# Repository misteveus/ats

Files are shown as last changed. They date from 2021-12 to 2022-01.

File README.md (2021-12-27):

# ats

## Remote
- 3.3v power and ground header
    - No OVP
    - No OCP
    - No polarity protection
    - Modules have their own decoupling caps
    - Modules have decoupling capacitors
- SPI header for LoRa module debug
- UART header for GPS module debug
- ICSP header for programming the PIC18
- LoRa module and SMD antenna
- GPS module and SMD antenna
- PIC18 controller
    - Controls SPI and UART

remote schematic  

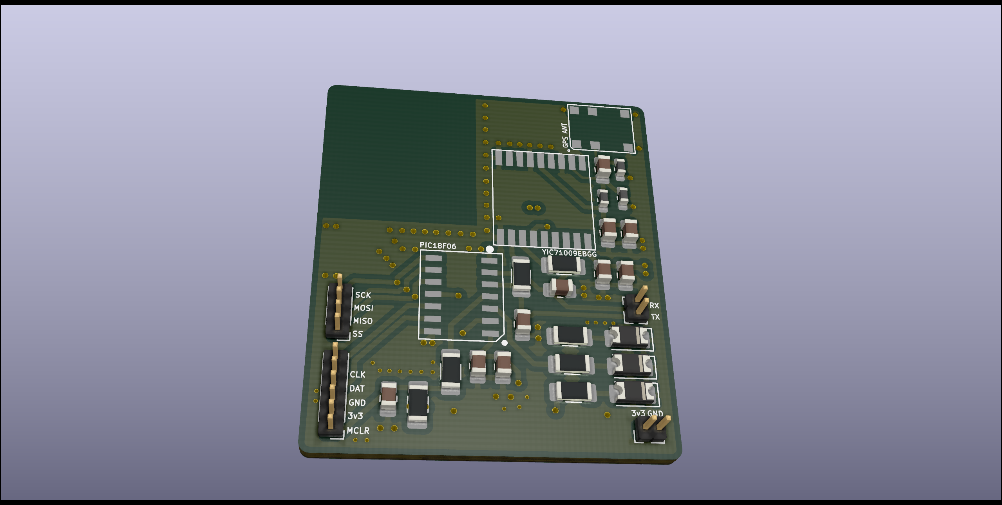
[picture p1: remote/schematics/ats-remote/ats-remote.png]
remote pcb
  

## References
Microcontroller PIC18F06Q40 [datasheet](https://ww1.microchip.com/downloads/aemDocuments/documents/MCU08/ProductDocuments/DataSheets/PIC18F06-16Q40-Data-Sheet-40002216D.pdf)  
LoRa Tranceiver RFM95W [datasheet](https://www.rfsolutions.co.uk/downloads/1463993415RFM95_96_97_98W.pdf)  
GPS/GLONASS Receiver YIC71009EBGG [datasheet](https://www.yic.com.tw/wp-content/uploads/2021/05/YIC71009EBGG.pdf)

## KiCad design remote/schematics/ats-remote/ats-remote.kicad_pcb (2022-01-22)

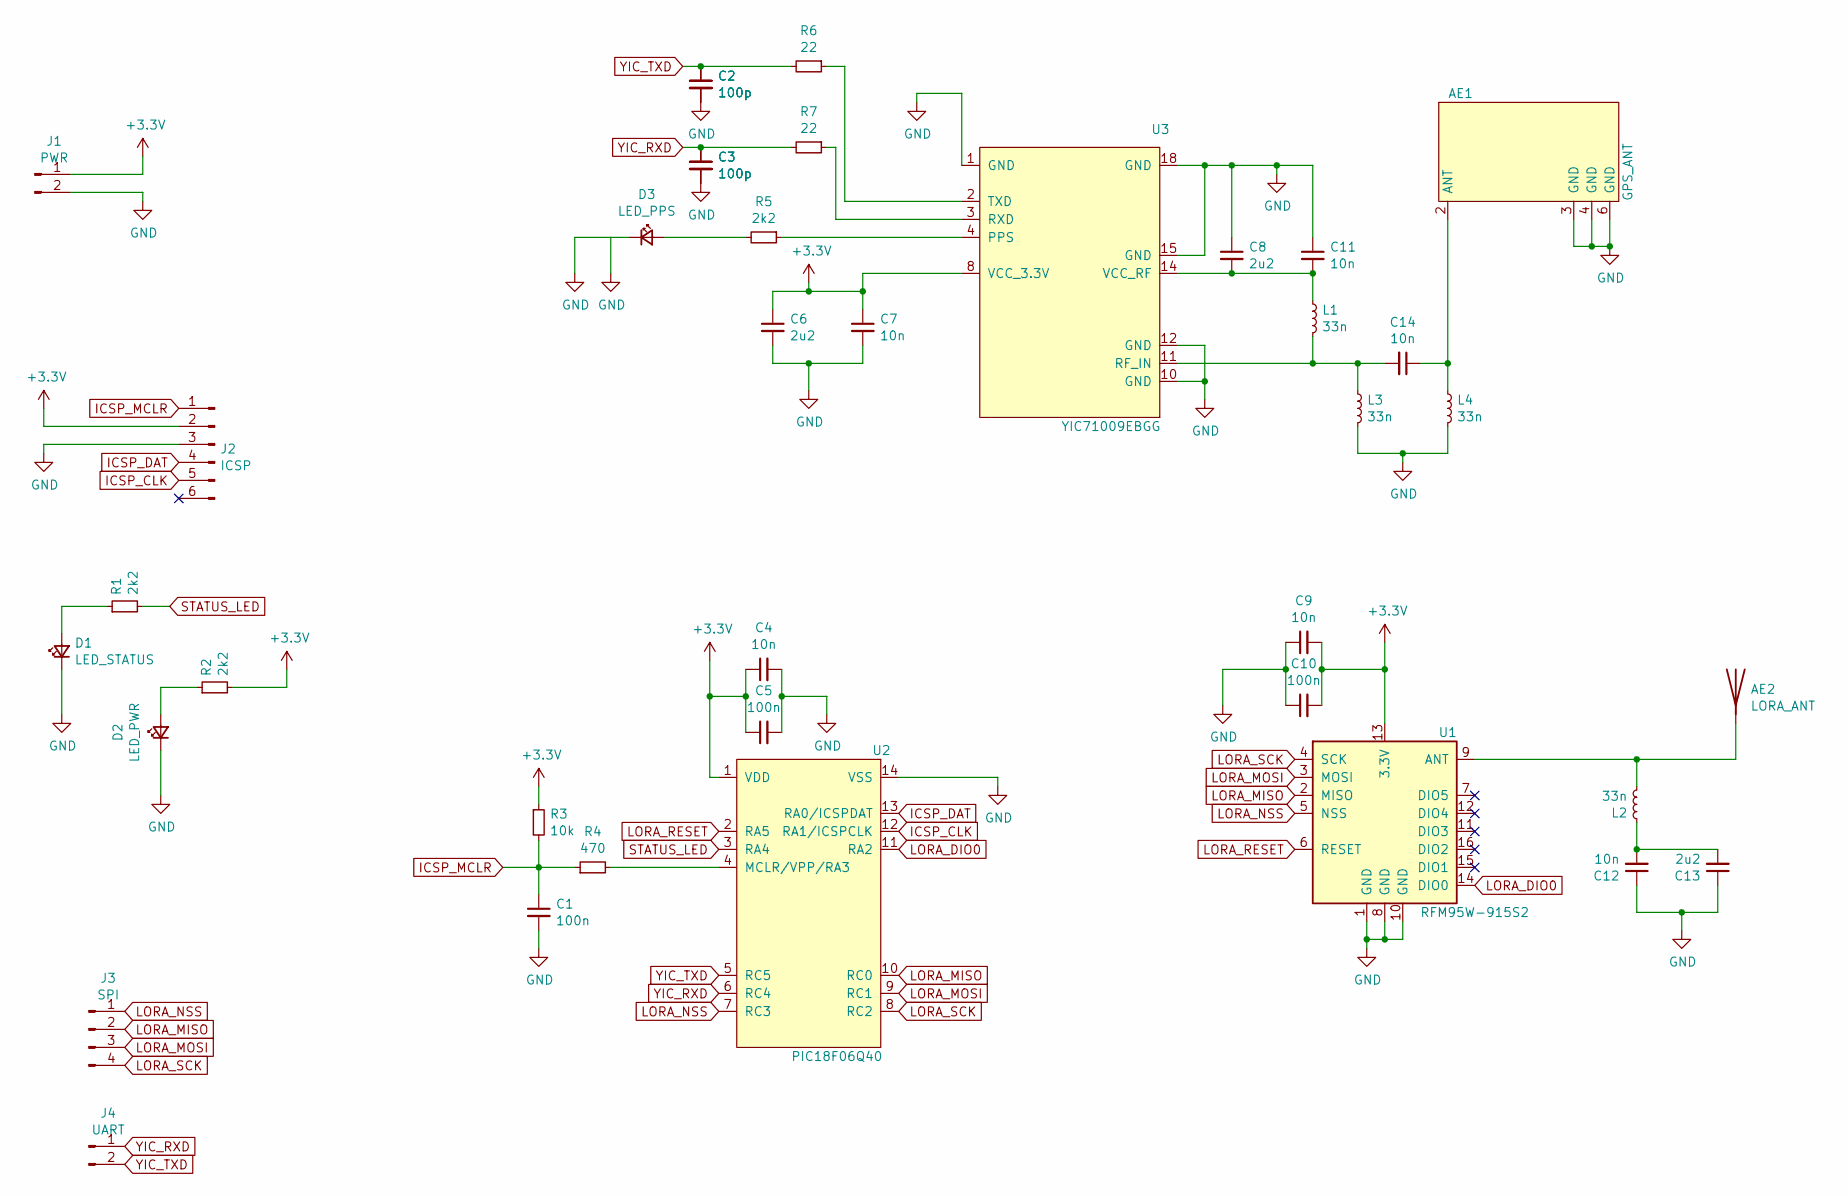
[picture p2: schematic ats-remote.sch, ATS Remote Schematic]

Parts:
AE1: GPS_ANT; GPS_ANT_SR4G008
AE2: LORA_ANT; LORA_ANT_YIC71009EBGG
C1, C5, C10: 100n; C_0805_2012Metric_Pad1.18x1.45mm_HandSolder
C2, C3: 100p; C_0805_2012Metric_Pad1.18x1.45mm_HandSolder
C4, C7, C9, C11, C12, C14: 10n; C_0805_2012Metric_Pad1.18x1.45mm_HandSolder
C6, C8, C13: 2u2; C_0805_2012Metric_Pad1.18x1.45mm_HandSolder
D1: LED_STATUS; D_1206_3216Metric_Pad1.42x1.75mm_HandSolder
D2: LED_PWR; D_1206_3216Metric_Pad1.42x1.75mm_HandSolder
D3: LED_PPS; D_1206_3216Metric_Pad1.42x1.75mm_HandSolder
J1: PWR; PinHeader_1x02_P1.27mm_Vertical
J2: ICSP; PinHeader_1x06_P1.27mm_Vertical
J3: SPI; PinHeader_1x04_P1.27mm_Vertical
J4: UART; PinHeader_1x02_P1.27mm_Vertical
L1, L2, L3, L4: 33n; L_0603_1608Metric_Pad1.05x0.95mm_HandSolder
R1, R2, R5: 2k2; R_1206_3216Metric_Pad1.30x1.75mm_HandSolder
R3: 10k; R_1206_3216Metric_Pad1.30x1.75mm_HandSolder
R4: 470; R_1206_3216Metric_Pad1.30x1.75mm_HandSolder
R6, R7: 22; R_1206_3216Metric_Pad1.30x1.75mm_HandSolder
U1: RFM95W-915S2; HOPERF_RFM9XW_SMD
U2: PIC18F06Q40; PIC18F06Q40-SOIC14
U3: YIC71009EBGG; YIC71009EBGG-19STAMP

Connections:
+3V3: C4.1, C5.1, C6.1, C7.1, C9.2, C10.2, J1.1, J2.2, R2.2, R3.1, U1.13 (3.3V), U2.1 (VDD), U3.8 (VCC_3.3V)
GND: AE1.3 (GND), AE1.4 (GND), AE1.6 (GND), C1.2, C2.2, C3.2, C4.2, C5.2, C6.2, C7.2, C8.1, C9.1, C10.1, C11.1, C12.1, C13.1, D1.1 (K), D2.1 (K), D3.1 (K), J1.2, J2.3, L3.2, L4.2, U1.1 (GND), U1.8 (GND), U1.10 (GND), U2.14 (VSS), U3.1 (GND), U3.10 (GND), U3.12 (GND), U3.15 (GND), U3.18 (GND)
ICSP_CLK: J2.5, U2.12 (RA1/ICSPCLK)
ICSP_DAT: J2.4, U2.13 (RA0/ICSPDAT)
ICSP_MCLR: C1.1, J2.1, R3.2, R4.1
LORA_DIO0: U1.14 (DIO0), U2.11 (RA2)
LORA_MISO: J3.2, U1.2 (MISO), U2.10 (RC0)
LORA_MOSI: J3.3, U1.3 (MOSI), U2.9 (RC1)
LORA_NSS: J3.1, U1.5 (NSS), U2.7 (RC3)
LORA_RESET: U1.6 (RESET), U2.2 (RA5)
LORA_SCK: J3.4, U1.4 (SCK), U2.8 (RC2)
unnamed: AE1.2 (ANT), C14.1, L4.1
unnamed: AE2.1, L2.2, U1.9 (ANT)
unnamed: C8.2, C11.2, L1.1, U3.14 (VCC_RF)
unnamed: C12.2, C13.2, L2.1
unnamed: C14.2, L1.2, L3.1, U3.11 (RF_IN)
unnamed: D1.2 (A), R1.1
unnamed: D2.2 (A), R2.1
unnamed: D3.2 (A), R5.2
unnamed: R4.2, U2.4 (MCLR/VPP/RA3)
unnamed: R5.1, U3.4 (PPS)
unnamed: R6.1, U3.2 (TXD)
unnamed: R7.1, U3.3 (RXD)
STATUS_LED: R1.2, U2.3 (RA4)
YIC_RXD: C3.1, J4.1, R7.2, U2.6 (RC4)
YIC_TXD: C2.1, J4.2, R6.2, U2.5 (RC5)

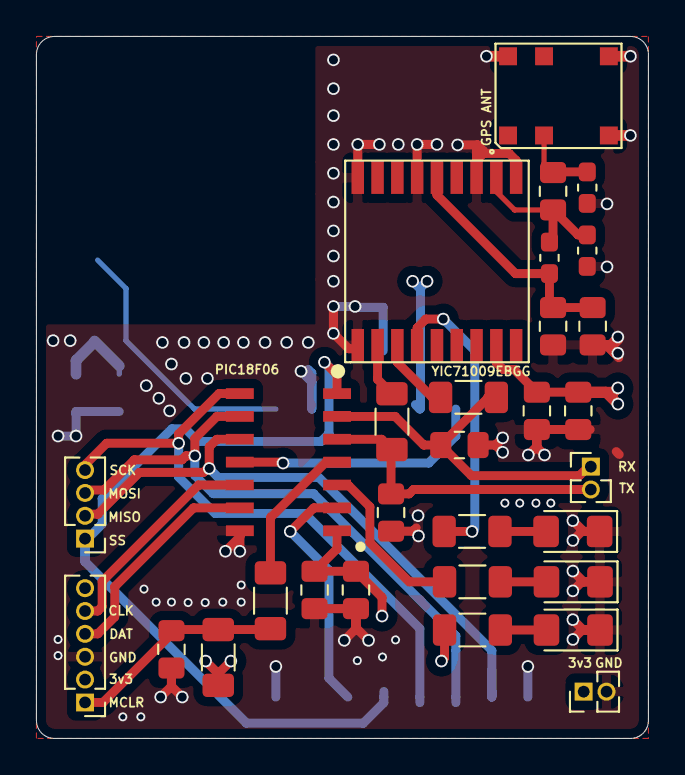
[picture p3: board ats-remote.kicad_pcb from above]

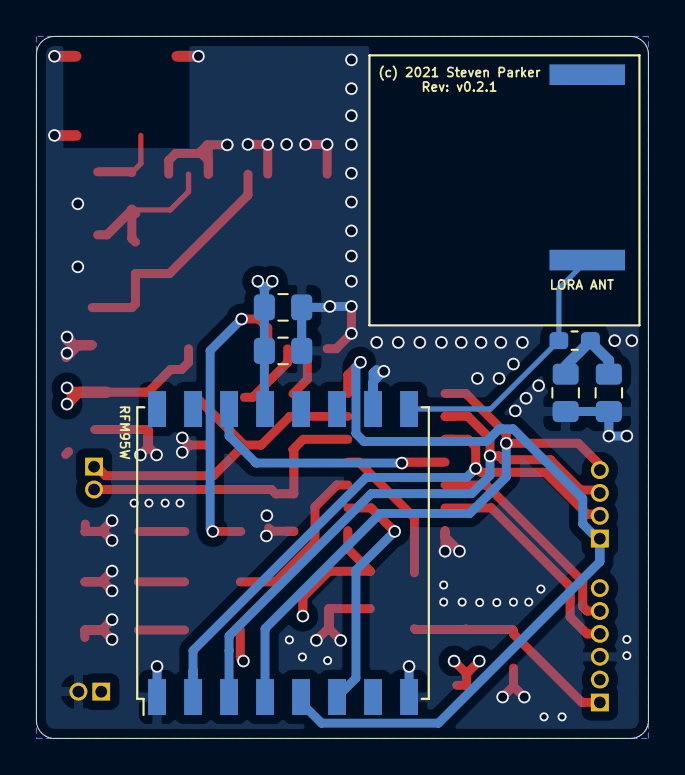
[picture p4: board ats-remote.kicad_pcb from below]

Board: 4 copper layers, 34.0 x 39.0 mm, 37 parts (7 on the bottom side), 26 nets.

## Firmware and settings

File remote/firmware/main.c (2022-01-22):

#include "devcfg.h"

#include <xc.h>

#include <interrupts.h>
#include <spi.h>
#include <uart.h>
#include <lora.h>

static uint8_t command[2] = { 0x06, 0x00 };
static uint8_t received[2];

void init(void);
void tmr0_init(void);
int main(void)
{
    init();
    
    while(1)
    {
        spi1_send(command, received, 2);
        
        // wait
        for (int i = 0; i < 10000; i++);
    } 
}

void init(void)
{
    interrupts_init();
    tmr0_init();
    spi1_init();
    uart_init();
    lora_init();
    
    TRISA &=  ~_TRISA_TRISA4_MASK;
}

void tmr0_init() {
    // Disable TMR0
    T0CON0bits.EN = 0;
    
    // TMR0 in 16-bit mode
    T0CON0bits.MD16 = 0;
    
    // TMR0 Postscaler(divider) 
    T0CON0bits.OUTPS = 0xf;
    
    // Clock source is Fosc / 4
    T0CON1bits.CS = 2;
    
    // clock is synchronized
    T0CON1bits.ASYNC = 0;
    
    // Prescaler
    T0CON1bits.CKPS = 0x8;
    
    TMR0H = 0x02;
    TMR0L = 0x00;
    
    // Enable low priority interrupt
    IPR3bits.TMR0IP = 0;
    PIE3bits.TMR0IE = 1;
    
    T0CON0bits.EN = 1;
}

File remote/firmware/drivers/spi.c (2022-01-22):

#include "spi.h"

void spi1_init(void) {
    // Disable SPI1 module
    SPI1CON0bits.EN = 0;
    
    // MSb first (default)
    SPI1CON0bits.SPI1LSBF = 0;
    
    // Operate as bus host
    SPI1CON0bits.SPI1MST = 1;
    
    // Host mode: Full-Duplex
    SPI1CON0bits.BMODE = 1;
    SPI1CON2bits.TXR = 1;
    SPI1CON2bits.RXR = 1;
   
    SPI1TWIDTH = 8; 
    
    // SDI sampled at middle of SDO output (default)
    SPI1CON1bits.SMP = 0;
    
    // SPI SCK:
    //   SCK low level is idle state (default); high level is active
    //   SDI polarity is active high (default)
    //   SDO polarity is active high (default)
    //   SPI1 clock equals system clock (default)
    SPI1CON1bits.CKP = 0;
    SPI1CON1bits.CKE = 1;
    SPI1CON1bits.SMP = 1;
    SPI1CON1bits.SDIP = 0;   
    SPI1CON1bits.SDOP = 0;
    SPI1CLKbits.CLKSEL = 0;
    
    // Chip Select is active low 
    SPI1CON1bits.SSP = 1;

    // Set the baud rate for SPI1 to ~9600 (Fbaud = Fosc / 2 * (BAUD + 1))
    SPI1BAUD = 52;
    
    // PPS Outputs:
    RC3PPS = 0x1D; // Set SPI1 SS to port RC3 pin 
    RC2PPS = 0x1B; // Set SPI1 SCK to port RC2 pin 
    RC1PPS = 0x1C; // Set SPI1 SDO to port RC1 pin 

    
    // PPS Inputs:
   // SPI1SDIPPS = 0x11; // Set SPI1 SDI to RC1 pin
 
    // Set RC3, RC2, RC1 to output mode
    TRISC &= ~_TRISC_TRISC3_MASK;
    TRISC &= ~_TRISC_TRISC2_MASK;
    TRISC &= ~_TRISC_TRISC1_MASK;
 
    // Enable SPI1 
    SPI1CON0bits.EN = 1;
}

// send_buff and recv_buff should both be not-null and have a size 
// the same size: sz (how much data to send/receive). Be aware that every byte 
// of data sent will read the response into the receive buffer whether 
// a response is expected or not.
void spi1_send(uint8_t *send_buff, uint8_t *recv_buff, size_t sz)
{
    if (send_buff == NULL || recv_buff == NULL || sz < 1)
    {
        return;
    }
    
    size_t buff_idx = 0;
    while (sz > 0) 
    {
        if (SPI1CON2bits.BUSY)
        {
            continue;
        }
        else
        {
            // Set total bytes to send
            SPI1TCNT = sz;
            
            // send next byte
            SPI1TXB = send_buff[buff_idx];
            
            // add sync delay before reading BUSY flag (up to 2 cycles)
            __asm("NOP");
            __asm("NOP");
            
            // wait until done sending
            while(SPI1CON2bits.BUSY) { };
            
            // read received byte
            recv_buff[buff_idx] = SPI1RXB;
            
            buff_idx++; 
            sz--;
        }
    }
}

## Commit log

2021-12-22 Add main.c and initial device config
2021-12-23 add kicad project files
    [ats-remote.kicad_pcb, ats-remote.sch]
2021-12-23 add footprints, schematic, and pcb for breakout board
    [ats-remote.kicad_pcb, ats-remote.sch]
2021-12-23 add gerber files
    [ats-remote-B_Cu.gbr, ats-remote-B_Mask.gbr, ats-remote-Edge_Cuts.gbr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]
2021-12-23 add schematic svg
2021-12-23 update schematic svg
    [ats-remote.sch]
2021-12-23 move gerber files to sub-directory and ignore autosave file
    [ats-remote-B_Cu.gbr, ats-remote-B_Mask.gbr, ats-remote-Edge_Cuts.gbr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]
2021-12-24 add drill files
    [ats-remote.kicad_pcb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]
2021-12-25 add footprints for gps and lora antennas; start work on new board
2021-12-25 update schematic and pcb to v0.2.0
    [ats-remote.kicad_pcb, ats-remote.sch]
2021-12-25 move remote schematic and pcb to v0.2.0 (#2)
    v0.2.0
    - 3.3v power and ground header
    - No OVP
    - No OCP
    - No polarity protection
    - Modules have their own decoupling caps
    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
    [ats-remote-B_Cu.gbr, ats-remote-B_Mask.gbr, ats-remote-Edge_Cuts.gbr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]
2021-12-25 remove gerber files
    [ats-remote.kicad_pcb]
2021-12-27 update schematic and pcb
    [ats-remote.kicad_pcb, ats-remote.sch]
2021-12-27 add silk screen
    [ats-remote.kicad_pcb]
2021-12-27 update silk screen
    [ats-remote.kicad_pcb]
2021-12-27 fix lora nss via and gps ant grounds
    [ats-remote.kicad_pcb]
2021-12-27 v0.2.1 (#3)
    * add footprints for gps and lora antennas; start work on new board
    * update schematic and pcb to v0.2.0
    * Update README.md
    * remove gerber files
    * update schematic and pcb
    * add silk screen
    * update silk screen
    * fix lora nss via and gps ant grounds
    [ats-remote.kicad_pcb, ats-remote.sch]
2021-12-27 update silkscreen to include copyright
    [ats-remote.kicad_pcb]
2022-01-17 add MPLAB X project (#4)
    * move driver module into the same src directory
    * add MPLAB X project files
2022-01-18 move io drivers to separate modules
2022-01-20 add module for interrupts
2022-01-20 update initerrupts init function to enable INT0 interrupt and priorities
2022-01-20 update interrupts init function to enable INT0 interrupt and priorities
2022-01-22 update spi drivers to fix several bugs and add tmr0 interrupt handler for status led
    [ats-remote.kicad_pcb, ats-remote.sch]

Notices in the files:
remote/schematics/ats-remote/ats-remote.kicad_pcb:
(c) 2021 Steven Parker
